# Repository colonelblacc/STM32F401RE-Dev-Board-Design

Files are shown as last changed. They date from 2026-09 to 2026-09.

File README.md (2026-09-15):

# STM32F401RETx — Custom PCB Design

> A compact, 2-layer custom PCB based on the **STM32F401RETx** microcontroller, featuring USB-C, SWD debugging, UART, SPI, I2C and GPIO expansion — designed in KiCad and fully verified with **0 DRC errors** and **0 ERC violations**.

---

## Board Preview

<p align="center">
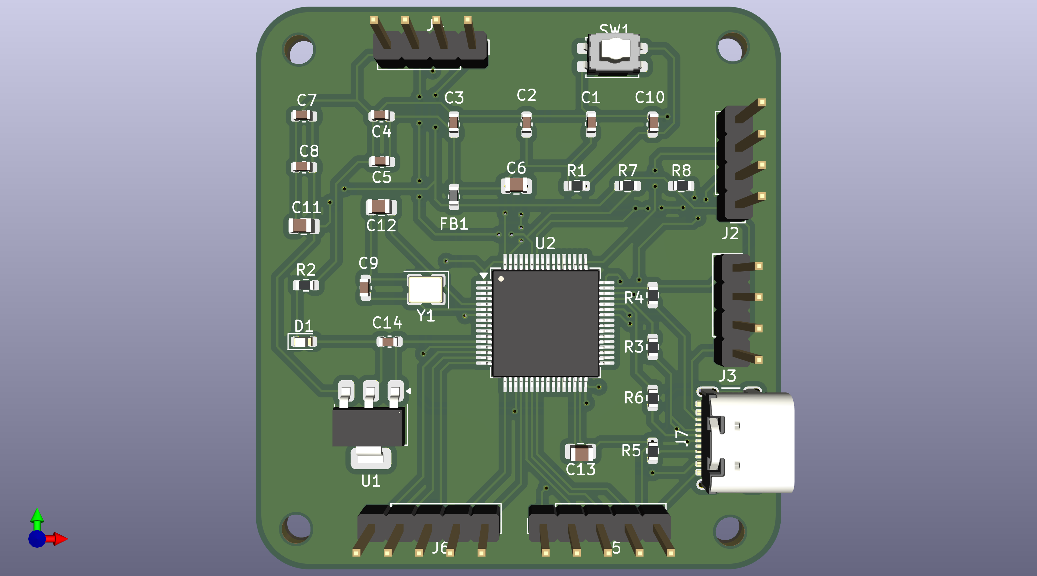
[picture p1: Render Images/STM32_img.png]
3D Render Top View
  
</p>

<p align="center">
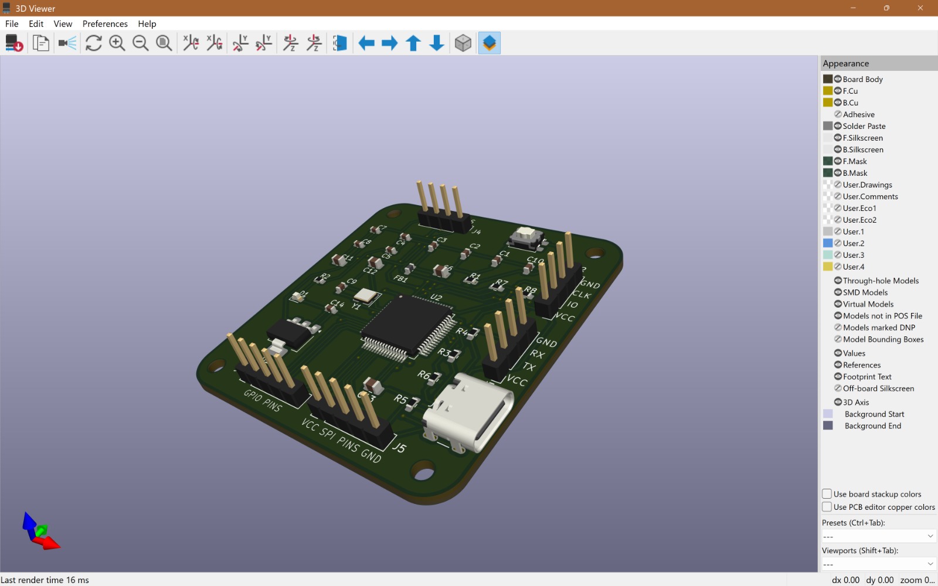
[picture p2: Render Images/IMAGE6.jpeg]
3D Perspective View
  
</p>

---

## Project Phases

This repository covers the complete design lifecycle:

| Phase | Contents | Status |
|---|---|---|
| Phase 1 | KiCad source files — schematic, PCB layout, project config | ✅ Complete |
| Phase 2 | 3D renders, layer exports, BOM, DRC/ERC verification, design report | ✅ Complete |

> **Phase 1** files (`STM32.kicad_sch`, `STM32.kicad_pcb`, `STM32.kicad_pro`) were uploaded in the first submission.
> **Phase 2** adds all supporting documentation, renders, and verification results — completing the full project.

---

## Repository Structure

```
STM32F401RE-Dev-Board-Design/
│
├── STM32.kicad_pcb                        # [Phase 1] KiCad PCB layout
├── STM32.kicad_pro                        # [Phase 1] KiCad project file
├── STM32.kicad_sch                        # [Phase 1] KiCad schematic
│
├── STM32_F401_Design_Report.pdf           # [Phase 2] Full design report
├── STM32_PDF.pdf                          # [Phase 2] Supplementary PDF
│
├── PCB Layout/
│   ├── STM32.zip                          # KiCad project archive
│   └── STM32_pcb_layer.zip                # Exported PCB layer files (Gerbers)
│
├── Render Images/
│   ├── STM32_img.png                      # 3D Render — Top View (clean)
│   ├── 3D Design.jpeg                     # 3D Render — KiCad Viewer Top
│   ├── IMAGE5.jpeg                        # 3D Render — PCB Back View
│   ├── IMAGE6.jpeg                        # 3D Render — Perspective View
│   ├── Layout Layer1.jpeg                 # F.Cu Front Copper Layer
│   ├── Layout Layer2.jpeg                 # B.Cu Back Copper Layer
│   ├── Schematic.jpeg                     # Full Schematic Diagram
│   ├── IMAGE1.jpeg                        # DRC Result — 0 Errors
│   └── IMAGE2.jpeg                        # ERC Result — 0 Violations
│
├── BOM/
│   ├── BOM.jpeg                           # Footprint Assignments View
│   └── BOM2.png                           # Bill of Materials Table
│
└── DRC ERC Results/
    ├── IMAGE1.jpeg     # DRC — 0 Violations
    └── IMAGE2.jpeg # ERC — 0 Violations
```

---

## Microcontroller

| Parameter | Details |
|---|---|
| **MCU** | STM32F401RETx |
| **Package** | LQFP-64 (10x10mm, 0.5mm pitch) |
| **Core** | ARM Cortex-M4 @ 84 MHz |
| **Flash** | 512 KB |
| **RAM** | 96 KB SRAM |
| **EDA Tool** | KiCad EDA 9.0.7 |
| **PCB Layers**  | 2 (F.Cu + B.Cu) |

---

## Features & Connectivity

| Interface | Connector/Ref | Description |
|---|---|---|
| **USB-C** | J7 | USB 2.0 (USB_C_Receptacle_USB3.0_C6P)|
| **GPIO** | J6 | 5-pin GPIO Expansion Header |
| **SPI** | J5 | VCC, SPI, GND Header |
| **UART** | J3 | TX / RX Header |
| **I2C** | J2 / J4 | SDA / SCL Header |
| **SWD** | J2 | SWDIO, SWDCLK, IO, VCC, GND |
| **RESET** | SW1 + J4 | Tactile push button + Reset pin header|
| **Power** | U1 (AMS1117)  | 3.3V LDO Regulator from USB 5V |
| **Crystal** | Y1 | 24 MHz SMD Crystal (3225-4Pin) |
| **LED** | D1 | Power / Status LED (0603) |

---

## Schematic

<p align="center">
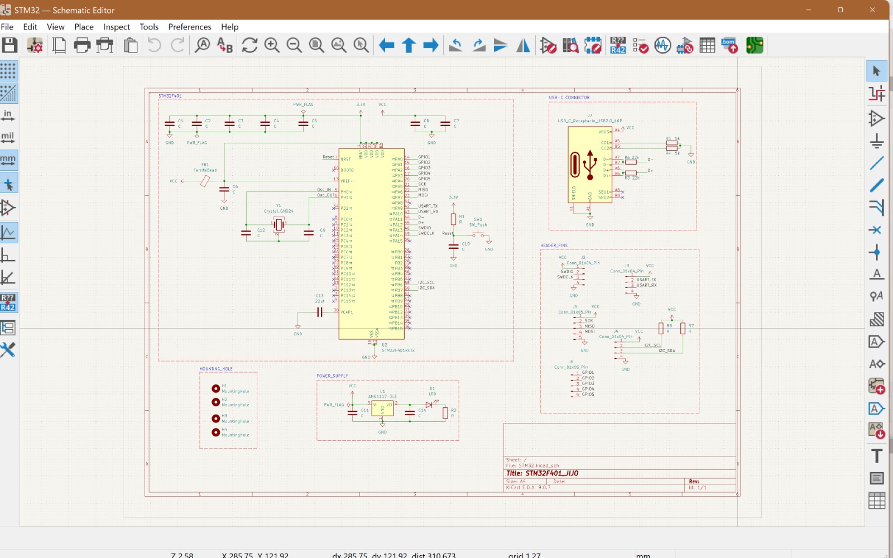
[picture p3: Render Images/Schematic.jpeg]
Schematic Diagram
  
</p>

The schematic is divided into functional blocks:

- **STM32F401** — Central MCU with all peripheral nets routed
- **Power Supply** — AMS1117-3.3 LDO with bulk and decoupling capacitors
- **USB-C Connector** — With 5.1k CC1/CC2 pull-down resistors (R7, R8)
- **Crystal** — 24 MHz with 22pF load capacitors C12, C13
- **Header Breakouts** — UART, SPI, I2C, GPIO, SWD
- **Mounting Holes** — H1–H4 (M2.5, 2.7mm diameter)

---

## PCB Layout

### Front Copper Layer — F.Cu
<p align="center">
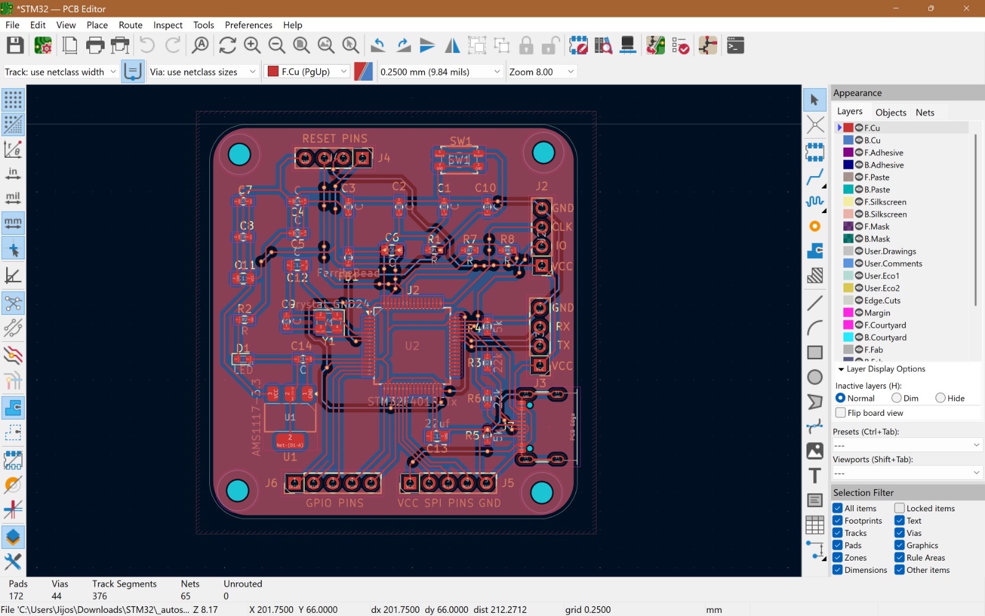
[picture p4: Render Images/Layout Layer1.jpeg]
Front Copper Layer
  
</p>

### Back Copper Layer — B.Cu
<p align="center">
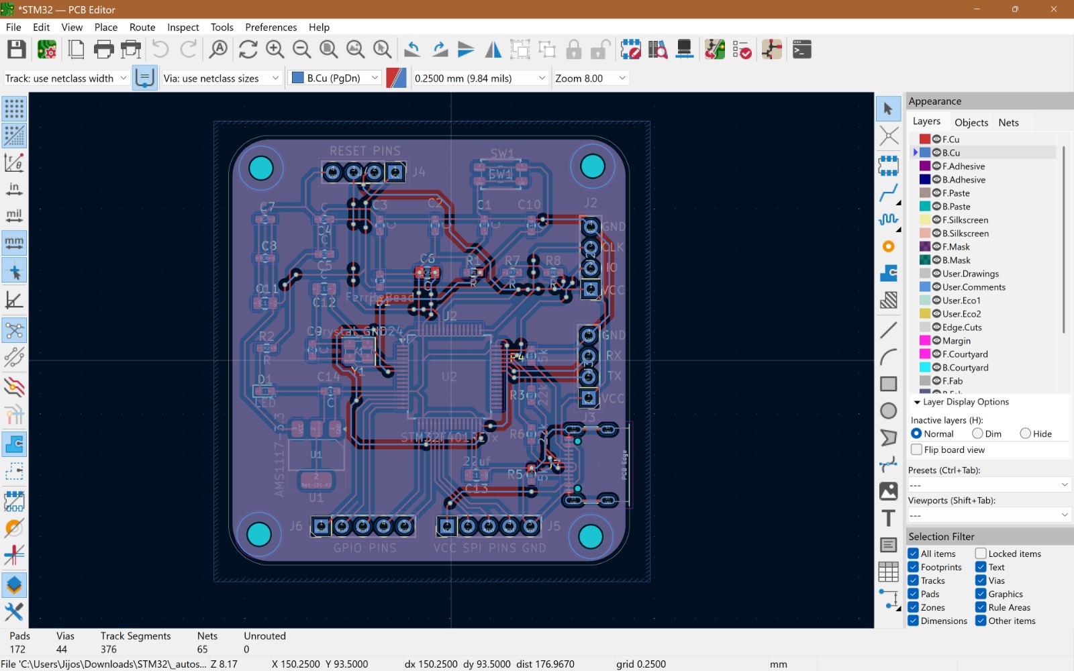
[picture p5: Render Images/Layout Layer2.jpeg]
Back Copper Layer
  
</p>

**PCB Statistics:**

| Parameter | Value |
|---|---|
| Pads | 172 |
| Vias | 44 |
| Track Segments | 376 |
| Nets | 65 |
| Unrouted | **0** |
| Track Width | 0.25 mm |

---

## Bill of Materials (BOM)

<p align="center">
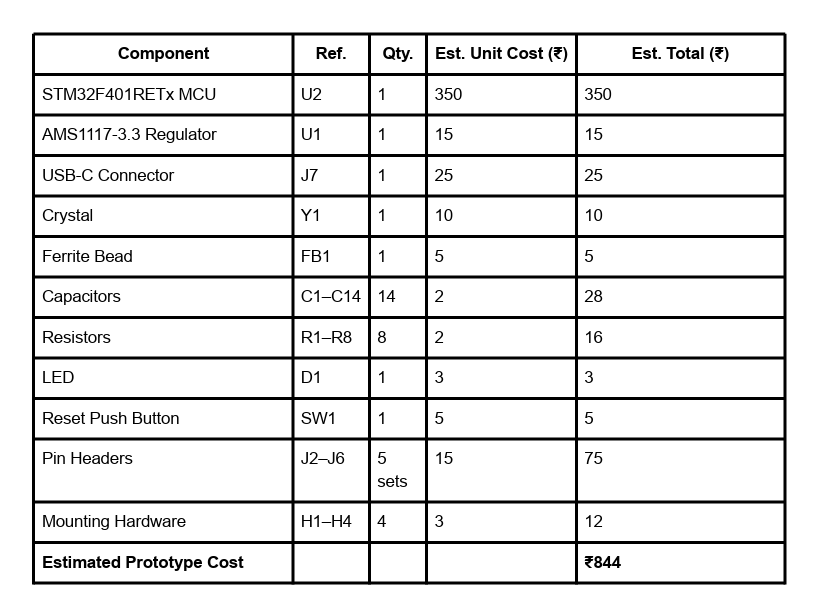
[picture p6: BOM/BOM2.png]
Bill of Materials
  
</p>

| Component | Ref. | Qty. | Est. Unit Cost | Est. Total  |
|---|---|---|---|---|
| STM32F401RETx MCU | U2 | 1 | Rs. 350 | Rs. 350 |
| AMS1117-3.3 Regulator  | U1 | 1 | Rs. 15 | Rs. 15 |
| USB-C Connector | J7 | 1 | Rs. 25 | Rs. 25 |
| Crystal 24 MHz | Y1 | 1 | Rs. 10 | Rs. 10 |
| Ferrite Bead | FB1 | 1 | Rs. 5 | Rs. 5 |
| Capacitors (0603/0805) | C1–C14  | 14 | Rs. 2 | Rs. 28 |
| Resistors (0603) | R1–R8 | 8 | Rs. 2 | Rs. 16 |
| LED (0603) | D1 | 1 | Rs. 3 | Rs. 3 |
| Reset Push Button | SW1 | 1 | Rs. 5 | Rs. 5 |
| Pin Headers 2.54mm | J2–J6 | 5 sets | Rs. 15 | Rs. 75 |
| Mounting Hardware M2.5 | H1–H4 | 4 | Rs. 3 | Rs. 12 |
| **Estimated Total** | | | | **Rs. 844** |

---

## DRC / ERC Verification

Both checks pass with **zero errors** — the design is fully clean.

### Design Rules Check (DRC) — 0 Violations

<p align="center">
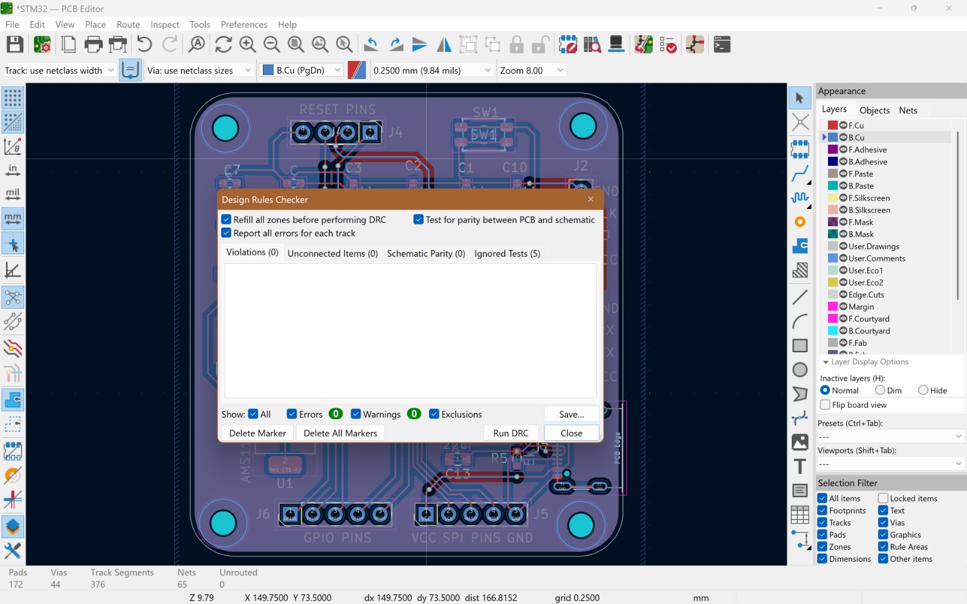
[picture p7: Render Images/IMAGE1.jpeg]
DRC — 0 Errors
  
</p>

| Check | Result |
|---|---|
| Violations | **0**  |
| Unconnected Items  | **0**  |
| Schematic Parity | **0**  |

### Electrical Rules Check (ERC) — 0 Violations

<p align="center">
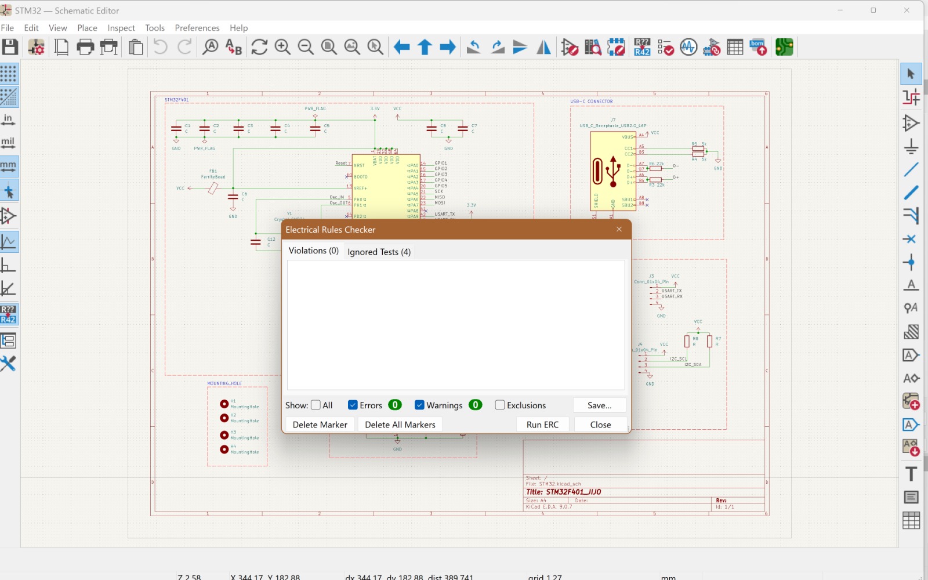
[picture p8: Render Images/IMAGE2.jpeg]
ERC — 0 Violations
  
</p>

| Check | Result |
|---|---|
| Errors | **0**  |
| Warnings | **0**  |

---

## 3D Renders

<table align="center">
  <tr>
    <td align="center">
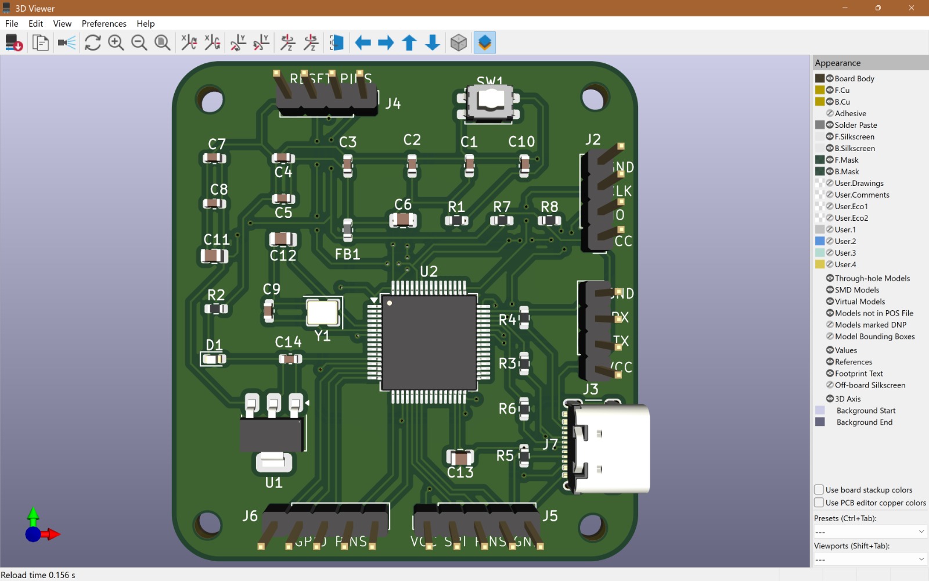
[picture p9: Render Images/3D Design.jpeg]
Top View
      <br/>
      <b>Top View — KiCad 3D Viewer</b>
    </td>
    <td align="center">
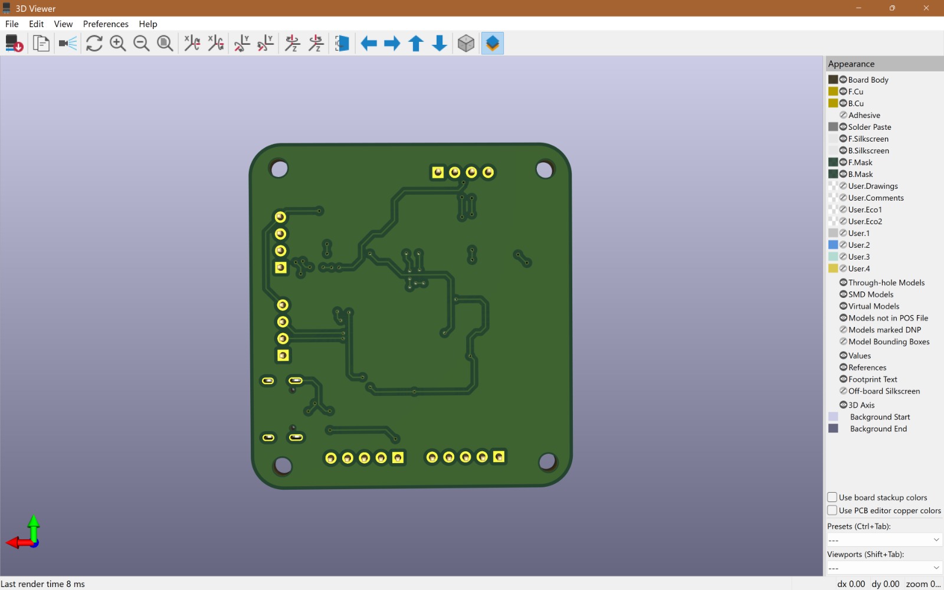
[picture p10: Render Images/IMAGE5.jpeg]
Bottom View
      <br/>
      <b>Bottom View</b>
    </td>
  </tr>
  <tr>
    <td align="center" colspan="2">
      Perspective View<br/>
      <b>Perspective View</b>
    </td>
  </tr>
</table>

---

## KiCad Source Files (Phase 1)

The raw KiCad design files are at the root of this repository:

| File | Description |
|---|---|
| `STM32.kicad_pcb`  | PCB Layout |
| `STM32.kicad_sch`  | Schematic |
| `STM32.kicad_pro`  | KiCad Project |

---

## Documents

| File | Description |
|---|---|
| `STM32_F401_Design_Report.pdf` | Full design report |
| `STM32_PDF.pdf` | Supplementary PDF |
| `PCB Layout/STM32.zip` | KiCad project archive |

---

## Tools Used

| Tool | Version | Purpose |
|---|---|---|
| **KiCad EDA** | 9.0.7 | Schematic + PCB Design |
| **KiCad 3D Viewer** | 9.0.7 | 3D Visualization |

---

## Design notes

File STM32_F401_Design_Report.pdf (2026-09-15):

# STM32 DEV BOARD

## Overview

- A compact custom STM32 development board designed in KiCad, integrating USB-C connectivity, regulated 3.3 V power, reset/boot access, debug interfaces, GPIO headers and SPI/I²C/UART expansion.
Design item | Implemented design
Microcontroller | STM32F401RETx
Power | USB/VCC input with AMS1117-3.3 regulator
USB | USB-C receptacle with USB 2.0 D+/D− and CC circuitry
Clock | External crystal Y1 with associated capacitors
Interfaces | SWD, UART, SPI, I²C and GPIO headers
PCB validation | DRC: 0 violations; 0 unconnected items
Schematic validation | ERC: 0 violations; 0 warnings

# 1. Problem Statement

The project addresses the need for a compact, reusable STM32F401-based development platform that can be programmed, debugged and connected to external electronics without requiring a separate breakout board. The design combines the microcontroller, power conditioning, USB-C interface, clock source, reset/boot controls and accessible signal headers on a single PCB.

# 2. Proposed Solution

A custom four-layer-capable-style compact PCB layout was developed in KiCad around the STM32F401RETx MCU. The schematic includes an AMS1117-3.3 linear regulator, local bypass capacitors, ferrite-bead power isolation, an external crystal, reset circuitry, USB-C connectivity and grouped headers for debug and peripheral signals. The resulting board is mechanically rounded at the corners and includes four mounting holes.

# 3. Circuit Architecture

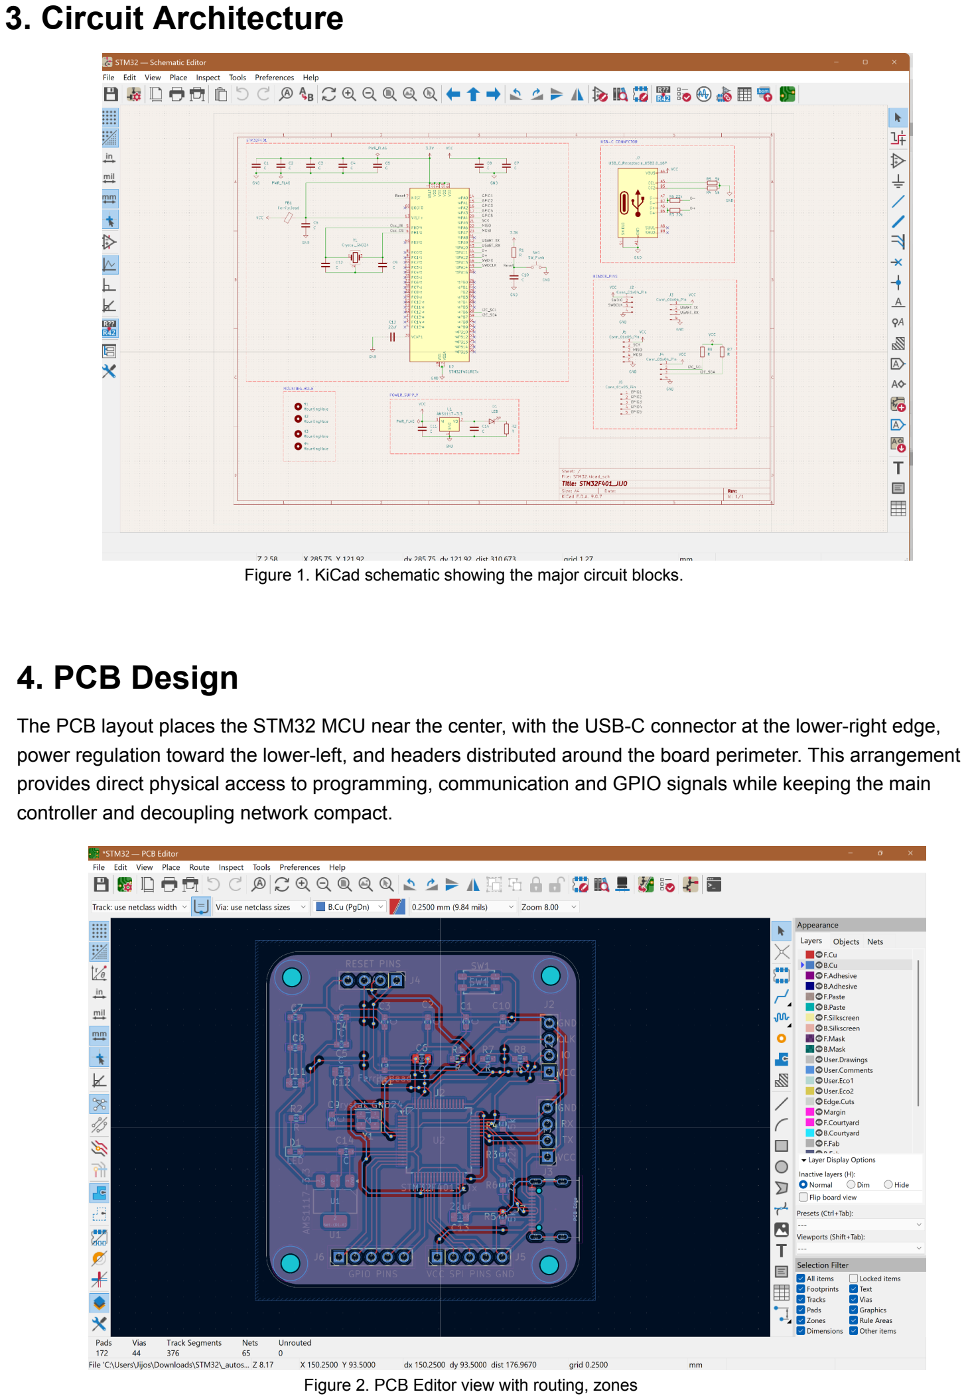
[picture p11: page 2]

Figure 1. KiCad schematic showing the major circuit blocks.

# 4. PCB Design

The PCB layout places the STM32 MCU near the center, with the USB-C connector at the lower-right edge, power regulation toward the lower-left, and headers distributed around the board perimeter. This arrangement provides direct physical access to programming, communication and GPIO signals while keeping the main controller and decoupling network compact.

Figure 2. PCB Editor view with routing, zones

# 5. Major Components

Reference | Component / function
U2 | STM32F401RETx — main 32-bit microcontroller
U1 | AMS1117-3.3 — 3.3 V linear regulator
J7 | USB-C USB 2.0 receptacle
Y1 | External crystal clock source
SW1 | Push-button reset/control input
FB1 | Ferrite bead for supply filtering
J2–J6 | GPIO, UART, SPI, I²C and debug/header access
C1–C14 | Supply, decoupling and clock-associated capacitors
D1 | LED indicator
H1–H4 | PCB mounting holes
Component | Ref. | Qty. | Est. Unit Cost (₹) | Est. Total (₹)
STM32F401RETx MCU | U2 | 1 | 350 | 350
AMS1117-3.3 Regulator | U1 | 1 | 15 | 15
USB-C Connector | J7 | 1 | 25 | 25
Crystal | Y1 | 1 | 10 | 10
Ferrite Bead | FB1 | 1 | 5 | 5
Capacitors | C1–C14 | 14 | 2 | 28
Resistors | R1–R8 | 8 | 2 | 16
LED | D1 | 1 | 3 | 3
Reset Push Button | SW1 | 1 | 5 | 5
Pin Headers | J2–J6 | 5 sets | 15 | 75
Mounting Hardware | H1–H4 | 4 | 3 | 12
Estimated Prototype Cost | | | | ₹844

# 6. Design Considerations

- Local decoupling capacitors are distributed around the MCU and power circuitry.
- The ferrite bead separates/filters the incoming supply path before the MCU rail.
- USB-C, SWD and peripheral signals are routed to accessible board-edge
headers/connectors.
- Four mounting holes support mechanical integration into a fixture or enclosure.
- The layout uses a continuous board outline with rounded corners and a compact component footprint.
- Silkscreen reference designators and interface labels are used to improve assembly and bring-up.

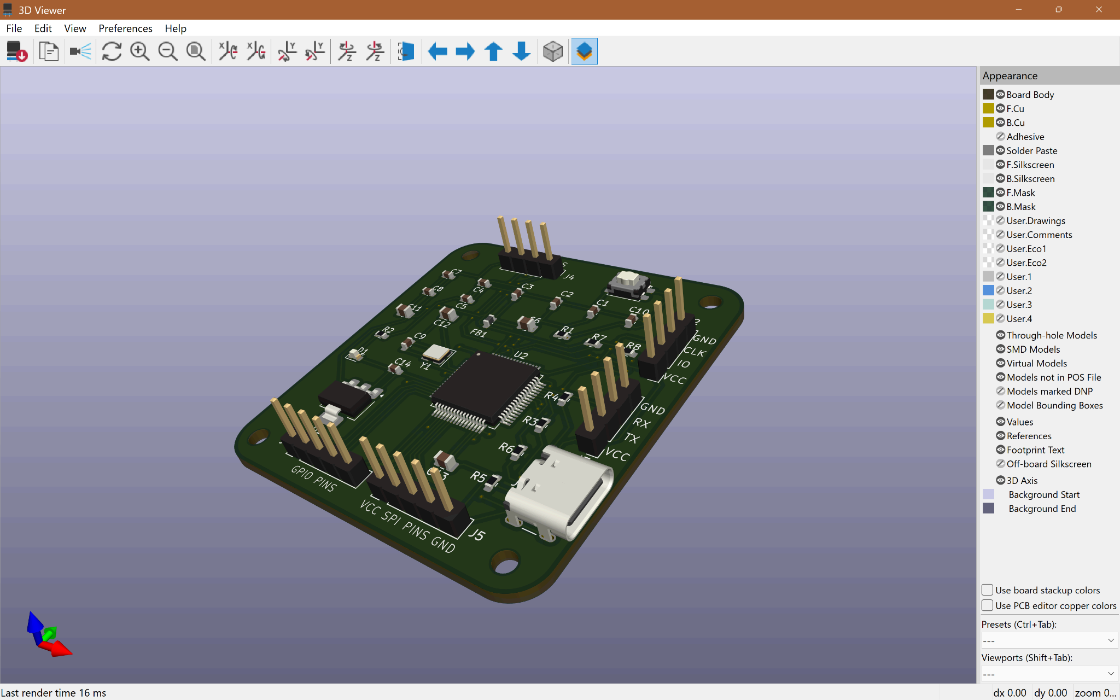
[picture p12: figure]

Figure 3. 3D view

# 7. Testing and Validation

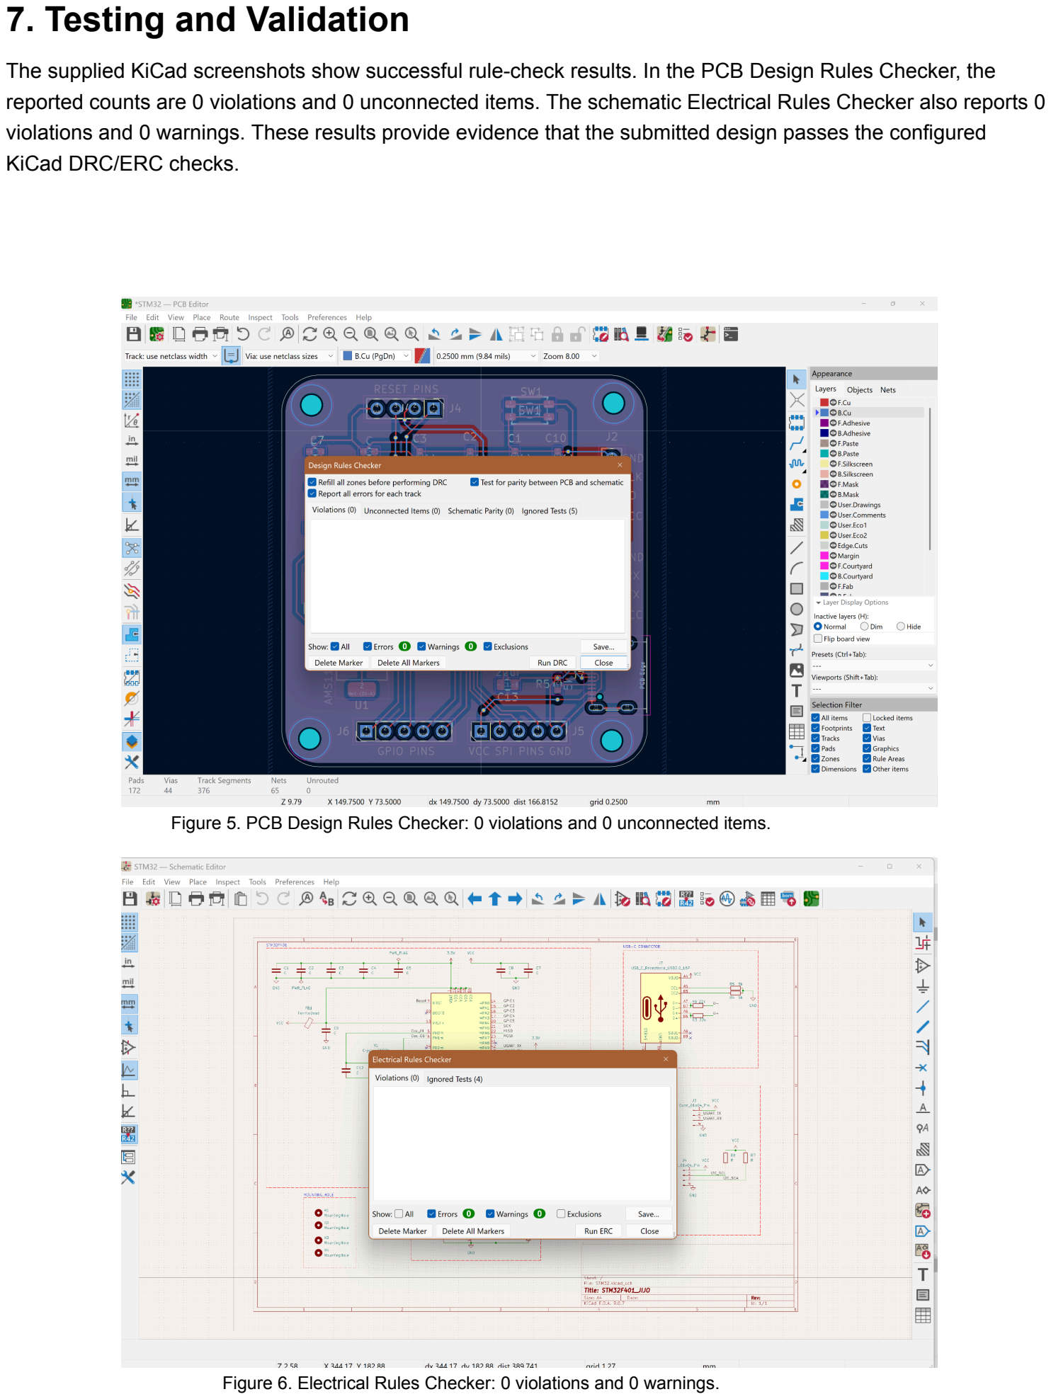
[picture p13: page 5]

The supplied KiCad screenshots show successful rule-check results. In the PCB Design Rules Checker, the reported counts are 0 violations and 0 unconnected items. The schematic Electrical Rules Checker also reports 0 violations and 0 warnings. These results provide evidence that the submitted design passes the configured KiCad DRC/ERC checks.

Figure 5. PCB Design Rules Checker: 0 violations and 0 unconnected items.

Figure 6. Electrical Rules Checker: 0 violations and 0 warnings.

The available evidence is CAD-level validation. No oscilloscope captures, electrical load tests, USB enumeration logs, thermal measurements or firmware test results were supplied, so those hardware-level results are not claimed in this report.

# 8. Challenges

The main design challenges are fitting the STM32 controller and supporting circuitry into a compact board, maintaining accessible connector placement, routing a dense set of MCU signals, and keeping power, clock and USB circuitry organized. Mechanical constraints such as the four mounting holes and edge-mounted USB-C connector also influence component placement and routing.

# 9. Final Outcome

The final design is a compact STM32F401RETx development board with USB-C, regulated 3.3 V power, external clocking, reset/boot access, debug connectivity and multiple peripheral/GPIO headers. The supplied PCB 3D views show a coherent assembled-board representation, while the reported KiCad DRC/ERC results show zero reported violations in the provided checks.

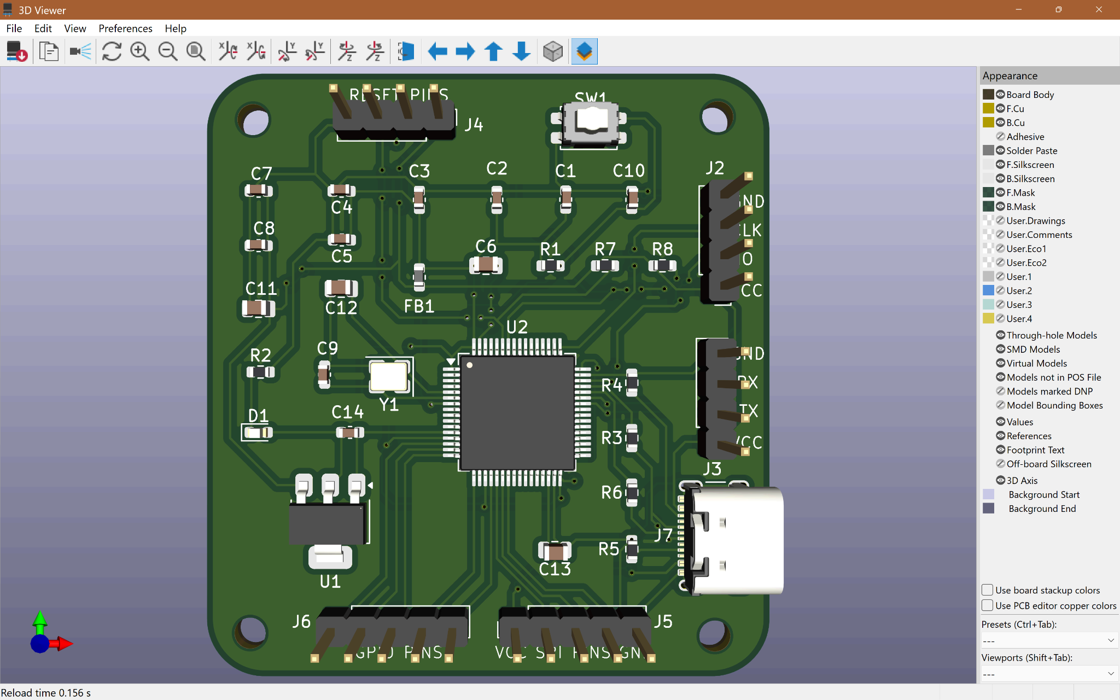
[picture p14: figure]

Figure 7. Final top-side 3D representation.

## Conclusion:

The design is suitable as a compact STM32 development platform and provides a strong basis for prototype fabrication and firmware bring-up. Before production release, hardware-level validation and a final manufacturing review should be completed.

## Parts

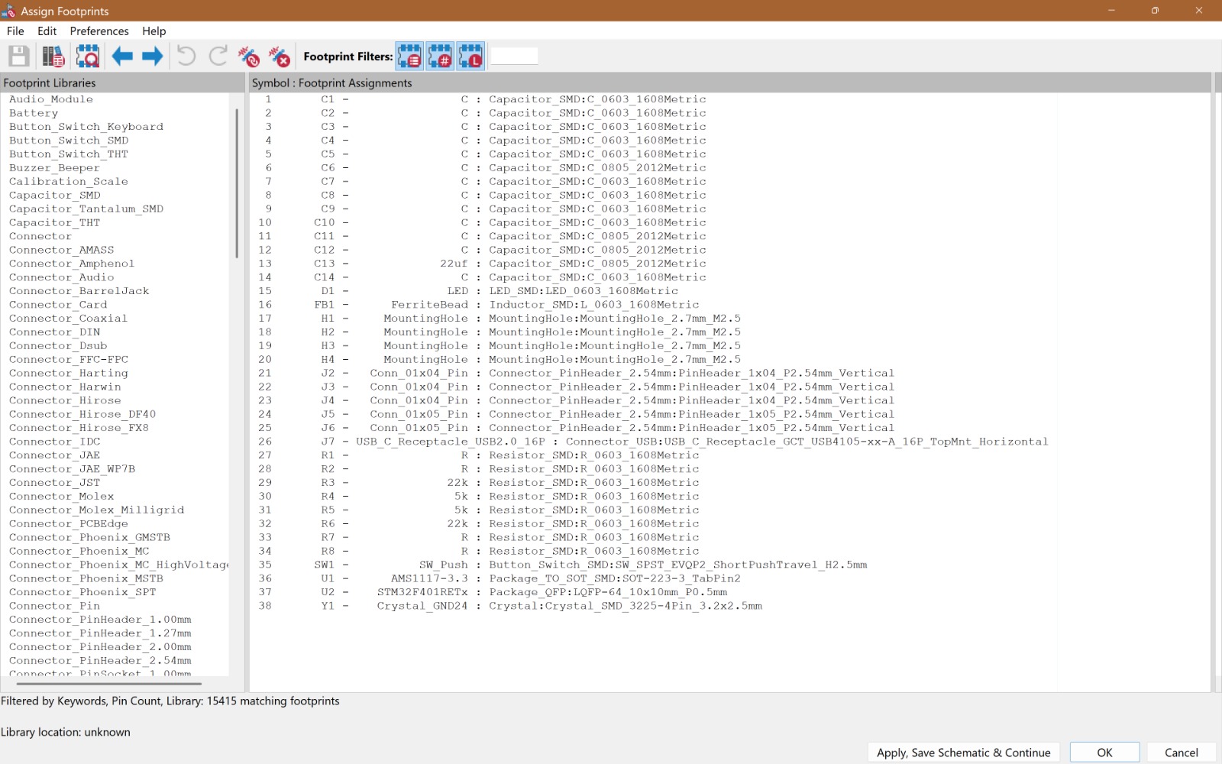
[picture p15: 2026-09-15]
BOM/BOM.jpeg

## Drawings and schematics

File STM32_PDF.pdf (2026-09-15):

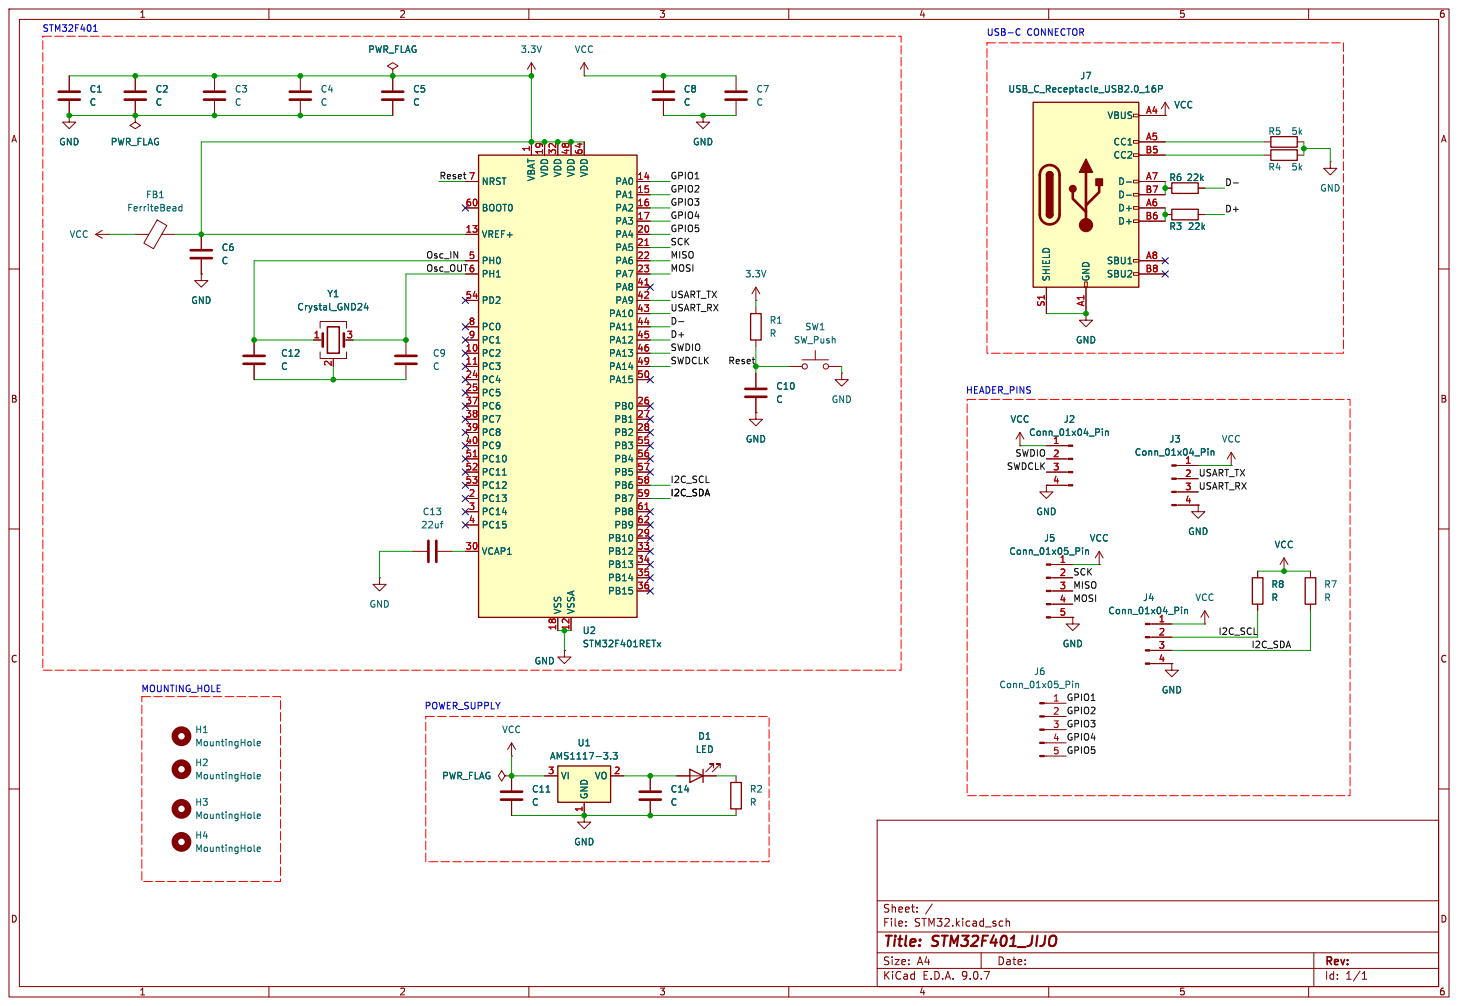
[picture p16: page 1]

1 VDD 19 VDD 32 VSS 18 VDD 48 VSSA 12 VDD 64 PA0 14 PA1 15 PA2 16 PA3 17 PA4 20 PA5 21 PA6 22 PA7 23 PA8 41 PA9 42 PA10 43 PA11 44 PA12 45 PA13 46 PA14 49 PA15 50 PB0 26 PB1 27 PB2 28 PB3 55 PB4 56 PB5 57 PB6 58 PB7 59 PB8 61 PB9 62 PB10 29 PB12 33 PB13 34 PB14 35 PB15 36 GND GND

1 VDD 19 VDD 32 VSS 18 VDD 48 VSSA 12 VDD 64 PA0 14 PA1 15 PA2 16 PA3 17 PA4 20 PA5 21 PA6 22 PA7 23 PA8 41 PA9 42 PA10 43 PA11 44 PA12 45 PA13 46 PA14 49 PA15 50 PB0 26 PB1 27 PB2 28 PB3 55 PB4 56 PB5 57 PB6 58 PB7 59 PB8 61 PB9 62 PB10 29 PB12 33 PB13 34 PB14 35 PB15 36 U2STM32F401RETx GND

H1 MountingHole H3 MountingHole H2 MountingHole H4 MountingHole

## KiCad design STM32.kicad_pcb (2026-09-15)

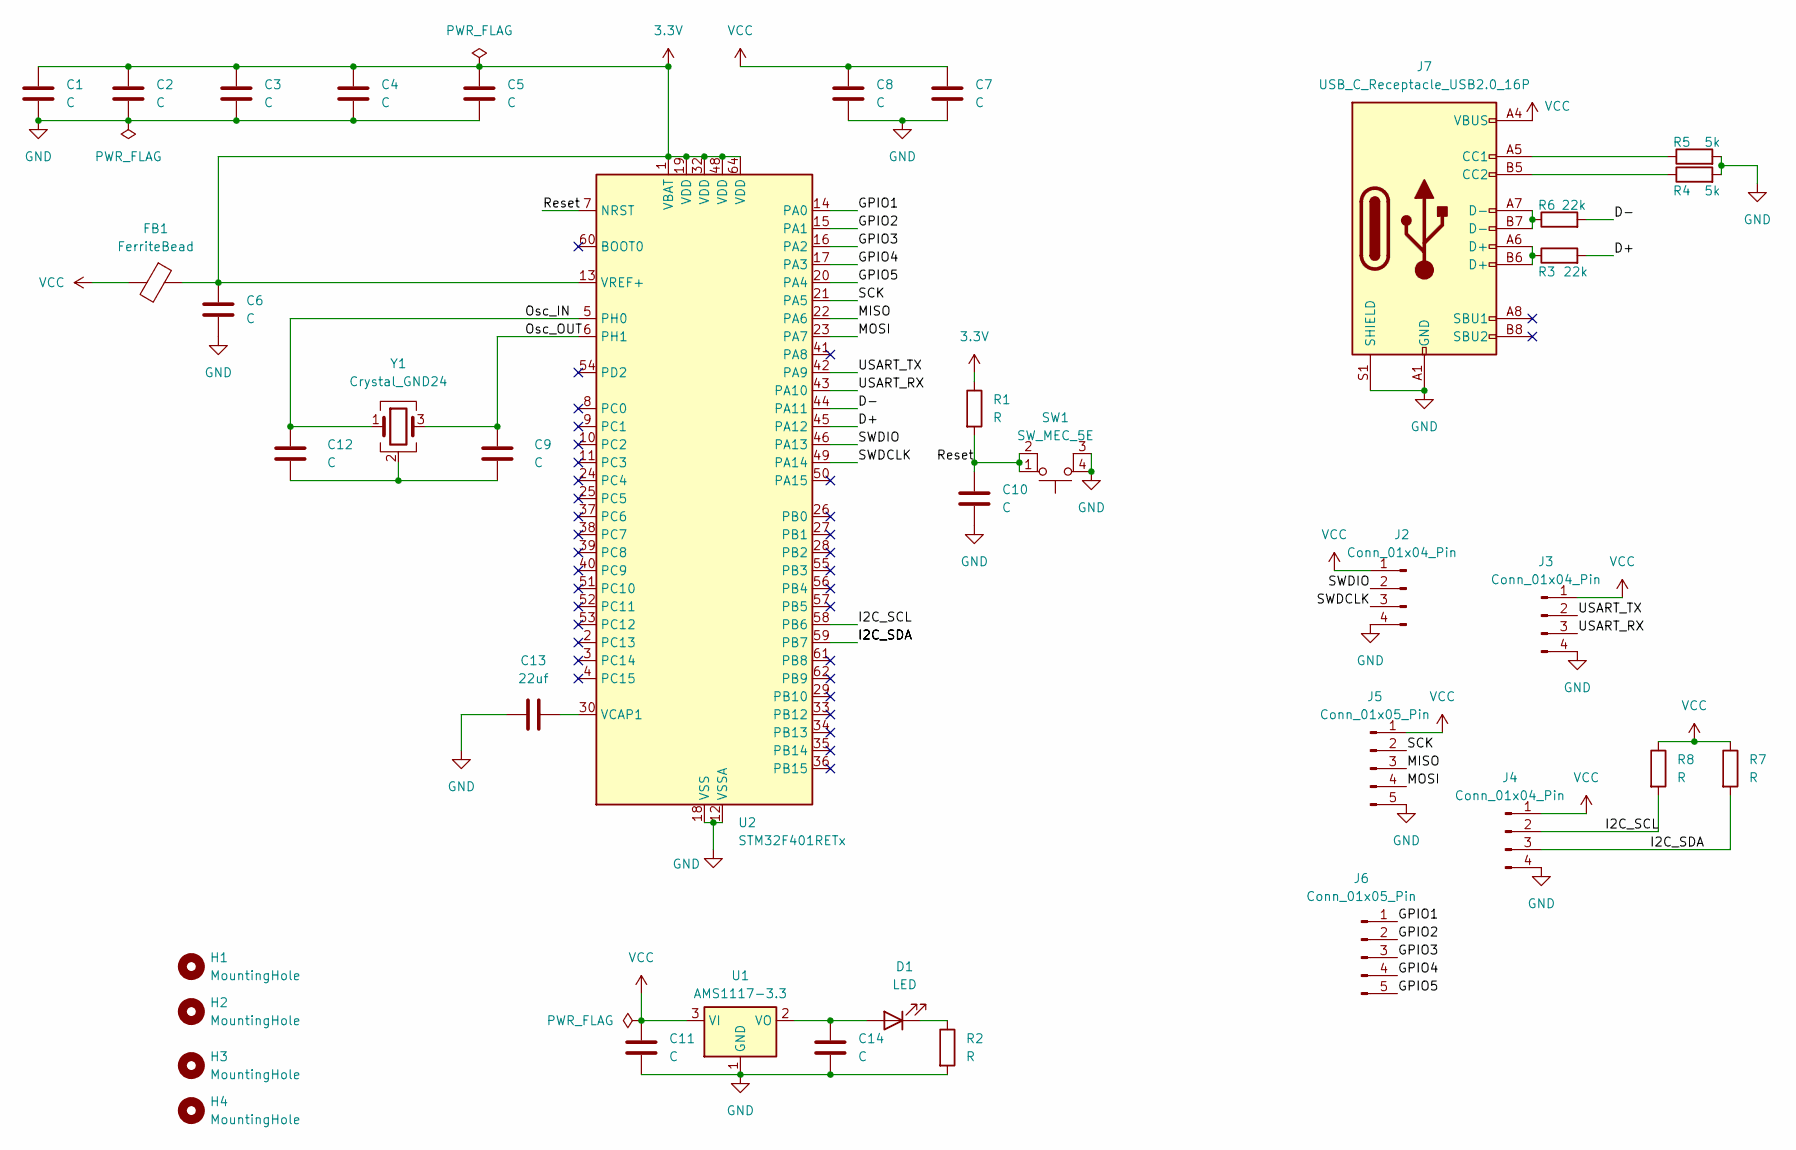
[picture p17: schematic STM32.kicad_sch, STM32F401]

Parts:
C1, C2, C3, C4, C5, C7, C8, C9, C10, C14: C; C_0603_1608Metric
C6, C11, C12: C; C_0805_2012Metric
C13: 22uf; C_0805_2012Metric
D1: LED; LED_0603_1608Metric
FB1: FerriteBead; L_0603_1608Metric
H1, H2, H3, H4: MountingHole; MountingHole_2.7mm_M2.5
J2, J3, J4: Conn_01x04_Pin; PinHeader_1x04_P2.54mm_Vertical
J5, J6: Conn_01x05_Pin; PinHeader_1x05_P2.54mm_Vertical
J7: USB_C_Receptacle_USB2.0_16P; USB_C_Receptacle_GCT_USB4105-xx-A_16P_TopMnt_Horizontal
R1, R2, R7, R8: R; R_0603_1608Metric
R3, R6: 22k; R_0603_1608Metric
R4, R5: 5k; R_0603_1608Metric
SW1: SW_MEC_5E; SW_Push_1P1T_NO_LED_E-Switch_TL1250
U1: AMS1117-3.3; SOT-223-3_TabPin2
U2: STM32F401RETx; LQFP-64_10x10mm_P0.5mm
Y1: Crystal_GND24; Crystal_SMD_3225-4Pin_3.2x2.5mm

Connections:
3.3V: C1.1, C2.1, C3.1, C4.1, C5.1, C6.1, FB1.1, R1.1, U2.1 (VBAT), U2.13 (VREF+), U2.19 (VDD), U2.32 (VDD), U2.48 (VDD), U2.64 (VDD)
/D+: R3.2, U2.45 (PA12)
/D-: R6.2, U2.44 (PA11)
/GPIO1: J6.1, U2.14 (PA0)
/GPIO2: J6.2, U2.15 (PA1)
/GPIO3: J6.3, U2.16 (PA2)
/GPIO4: J6.4, U2.17 (PA3)
/GPIO5: J6.5, U2.20 (PA4)
/I2C_SCL: J4.2, R8.2, U2.58 (PB6)
/I2C_SDA: J4.3, R7.2, U2.59 (PB7)
/MISO: J5.3, U2.22 (PA6)
/MOSI: J5.4, U2.23 (PA7)
/Osc_IN: C12.1, U2.5 (PH0), Y1.1
/Osc_OUT: C9.1, U2.6 (PH1), Y1.3
/Reset: C10.1, R1.2, SW1.1, SW1.2, U2.7 (NRST)
/SCK: J5.2, U2.21 (PA5)
/SWDCLK: J2.3, U2.49 (PA14)
/SWDIO: J2.2, U2.46 (PA13)
/USART_RX: J3.3, U2.43 (PA10)
/USART_TX: J3.2, U2.42 (PA9)
GND: C1.2, C2.2, C3.2, C4.2, C5.2, C6.2, C7.2, C8.2, C10.2, C11.2, C13.1, C14.2, J2.4, J3.4, J4.4, J5.5, J7.A1 (GND), J7.A12 (GND), J7.B1 (GND), J7.B12 (GND), J7.S1 (SHIELD), R2.2, R4.2, R5.2, SW1.3 (K), SW1.4 (A), U1.1 (GND), U2.12 (VSSA), U2.18 (VSS), U2.31 (VSS), U2.47 (VSS), U2.63 (VSS); also elsewhere on the board
unnamed: C9.2, C12.2, Y1.2 (G), Y1.4 (G)
unnamed: C14.1, D1.2 (A), U1.2 (VO)
unnamed: D1.1 (K), R2.1
unnamed: J7.A5 (CC1), R5.1
unnamed: J7.B5 (CC2), R4.1
unnamed: J7.A6 (D+), J7.B6 (D+), R3.1
unnamed: J7.A7 (D-), J7.B7 (D-), R6.1
unnamed: C13.2, U2.30 (VCAP1)
VCC: C7.1, C8.1, C11.1, FB1.2, J2.1, J3.1, J4.1, J5.1, J7.A4 (VBUS), J7.A9 (VBUS), J7.B4 (VBUS), J7.B9 (VBUS), R7.1, R8.1, U1.3 (VI); also elsewhere on the board

Board: 2 copper layers, 39 parts (0 on the bottom side), 32 nets, no tracks yet.

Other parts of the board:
J1: USB_C_Receptacle_USB2.0_14P; USB_C_Receptacle_HRO_TYPE-C-31-M-12

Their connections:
GND: J1.A1 (GND), J1.A12 (GND), J1.B1 (GND), J1.B12 (GND), J1.S1 (SHIELD); also elsewhere on the board
unnamed: J1.A6 (D+), J1.B6 (D+)
unnamed: J1.A7 (D-), J1.B7 (D-)
VCC: J1.A4 (VBUS), J1.A9 (VBUS), J1.B4 (VBUS), J1.B9 (VBUS); also elsewhere on the board
